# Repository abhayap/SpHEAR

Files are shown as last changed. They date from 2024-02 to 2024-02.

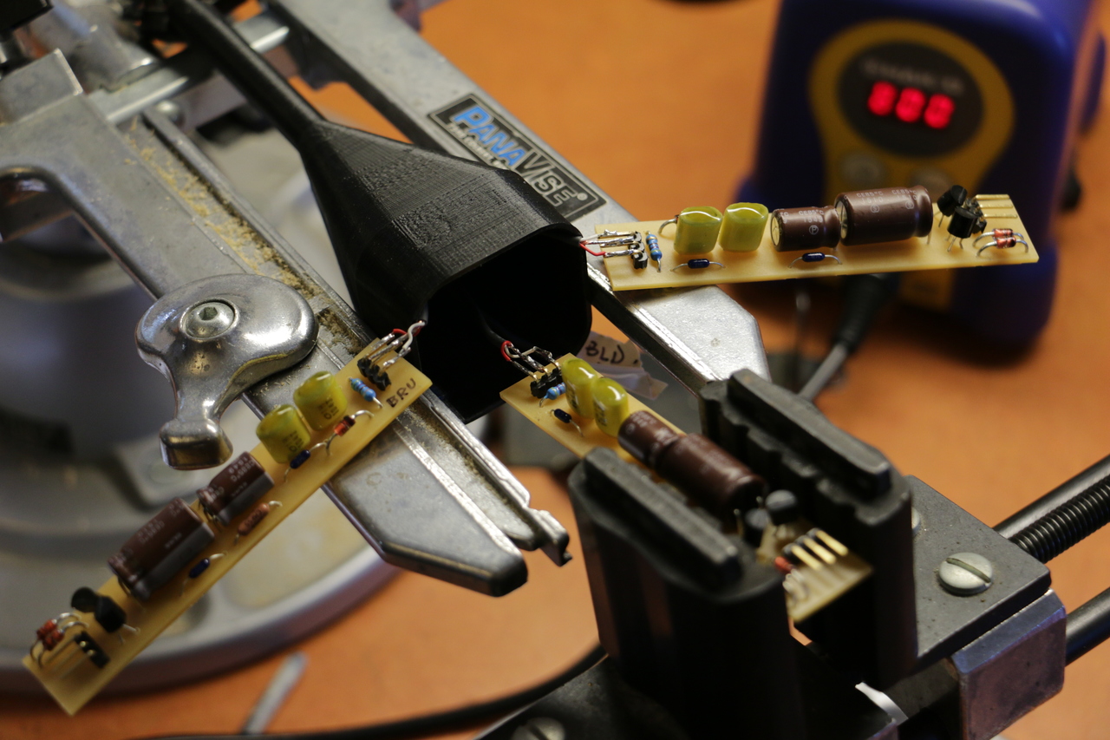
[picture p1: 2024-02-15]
pictures/TinySpHEAR_zapnspark_2.png

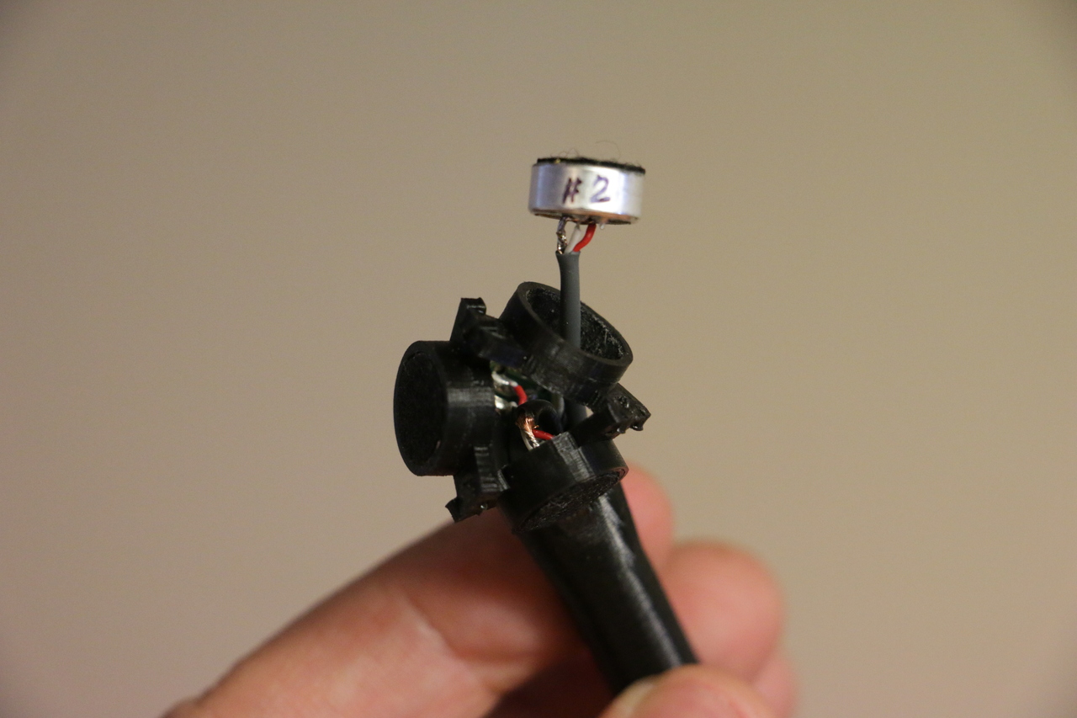
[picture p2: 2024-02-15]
pictures/TinySpHEAR_zapnspark_1.png

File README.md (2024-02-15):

# The *SpHEAR Project

The *SpHEAR (Spherical Harmonics Ear) Project is a collection of 3D models and associated code for building, testing and calibrating full surround Ambisonics microphones. All 3D models are written in Openscad with the code licensed under the GPL 3+ license (GNU Public License version 3 or higher), and the 3D models licensed under the Creative Commons Attribution-NonCommercial-ShareAlike 4.0 International license.

The 3D models are almost completely parametric and are designed to be able to be printed on low cost widely available 3D printers (at CCRMA we use an Ultimaker 2 Extended Plus printer, using PLA material). The design is modular and tries to avoid using overhangs and support structures. That is why each microphone assembly is made of a number of independently printed capsule holders interconnected by legs that interlock and hold the structure together. The capsule holders and the mount are glued together to create a 3D structure that securely holds all microphone capsules. A mount that can be clipped into a standard microphone stand is part of the design.

## Mailing list

You can subscribe to a development mailing list (sphear-devel@ccrma.stanford.edu) here:
<https://cm-mail.stanford.edu/mailman/listinfo/sphear-devel>

## About building microphones

Successfully printing a microphone assembly is only the first step in a long and complicated process. This also includes finding and buying the required microphone capsules, assembling the electronics (requires precision skill with the soldering iron) and finally calibrating the multi-capsule microphone to get the best performance out of it (you will need at least a single driver sound source and a calibrated microphone).

The whole process is not easy and requires knowledge of acoustics and electronics, plus a healthy dose of patience and the ability to perform tasks with precision and care. This repository will eventually include more detailed instructions, electronic schematics, suggested and tested parts and software and procedures for calibrating and measuring the microphone, including models for test and calibration rigs.

## 3D models

The 3D models currently include the TinySpHEAR, a four capsule first order Ambisonics microphone, the Octathingy, an eight capsule second order design by Eric Benjamin and Aaron Heller and preliminary designs for 12 and 20 capsule designs (the BigSpHEAR_12 and BigSpHEAR_20 models). The models will be expanded as testing proceeds. 

* [TinySpHEAR](doc/TinySpHEAR_simple.md): four capsule first order microphone with simple stand mount

  * [TinySpHEAR Zapnspark](doc/TinySpHEAR_zapnspark.md): four capsule first order microphone with four Zapnspark phantom power interfaces and shock mount

* [Octathingy](): eight capsule microphone (proof of concept so far)

* [BigSpHEAR_12 / BigSpHEAR_20](): 12 and 20 capsule designs (proof of concept)

## Electronics

The pcb/zapnspark directory contains the Kicad electrical circuit and printed circuit board design for the Zapnspark phantom power interface. The current printed circuit board design fits into four slots carved inside the body of the [TinySpHEAR plus Zapnspark model](doc/TinySpHEAR_zapnspark.md). Everything is dimensioned for the sizes of the components specified in the parts list, any changes (specially the diameter of the electrolytic capacitors) would need to be taken into account by changing appropriate model parameters. 

## Calibration

The calibration/src directory contains the Octave files for the current calibration software. The CALIBRATION.md file in there has a very brief description of usage, but currently is out of date with the current source code. Look into the individual files for more guidance. Hopefully this will be fixed soon.

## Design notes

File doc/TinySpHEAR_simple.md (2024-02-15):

# The *SpHEAR Project

## TinySpHEAR

The TinySpHEAR microphone is a traditional 4 capsule tetrahedral first order Ambisonics microphone. The picture shows the full design as previewed in OpenSCAD and a picture of the first prototype (built with Primo EM182 10mm capsules, 9.6mm microphone radius). 



The four capsule holders come in two flavors, one for the upper two capsules and another for the bottom two capsules that connect into the microphone mount. The capsule holders have legs with fingers that interlock and hold the structure together. There are two styles of usable interconnections, horizontal legs (easier to print and assemble, a bit bigger) and vertical legs (more difficult to print and assemble but more compact).

Horizontal legs, 10mm capsule, 10mm microphone radius:



Vertical legs, 10mm capsule, 10.6mm microphone radius:



There is a third style of legs intended to print the whole microphone structure in one go in a more sophisticated 3D printer, but this has not been tested.

TinySpHEAR, angled legs TinySpHEAR with angled legs

A couple of configuration variables in the source file can be used to switch to a "print" rendering where the individual parts of the structure are laid flat on the printing surface.

TinySpHEAR ready to print

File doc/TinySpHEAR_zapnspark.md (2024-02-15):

# The *SpHEAR Project

## TinySpHEAR with Zapnspark interfaces

The TinySpHEAR microphone is a traditional 4 capsule tetrahedral first order Ambisonics microphone. This improved design adds four printed circuit boards with Zapnspark phantom power interfaces housed in the microphone body. A trailing cable ends in four XLR connectors. The picture shows the full design as previewed in OpenSCAD and a picture of the second prototype (built with Primo EM182 10mm capsules, 9.6mm microphone radius).



The 3D models also include a shock mount that clips into a standard microphone stand mount. The two main model files are tuned for [EM182](../master/TinySpHEAR_EM182.scad "TinySpHEAR for 10mm EM182 capsules") (10mm) and [EM200](../master/TinySpHEAR_RM200.scad "TinySpHEAR for EM200 capsules") (14mm) capsules. Uncomment the different "render_" lines to render different parts or the complete microphone assembly. 

A few more pictures detailing the assembly process:

Wiring the capsules:



Connecting the capsules with the printed circuit boards:



Sliding the printed circuit boards into the slots in the body:



Connecting to the 4 conductor cable:



Ready to test:



The full microphone including the shock mount:



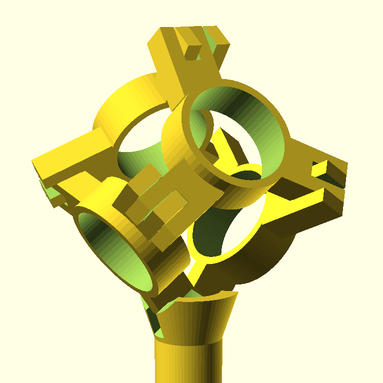
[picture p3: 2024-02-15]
pictures/TinySpHEAR_10mm_hlegs.png

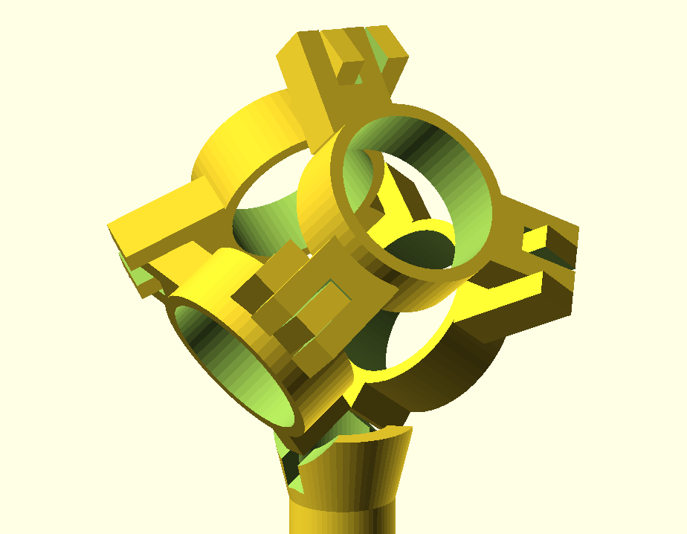
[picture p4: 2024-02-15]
pictures/TinySpHEAR_hlegs_10mm_10mm.png

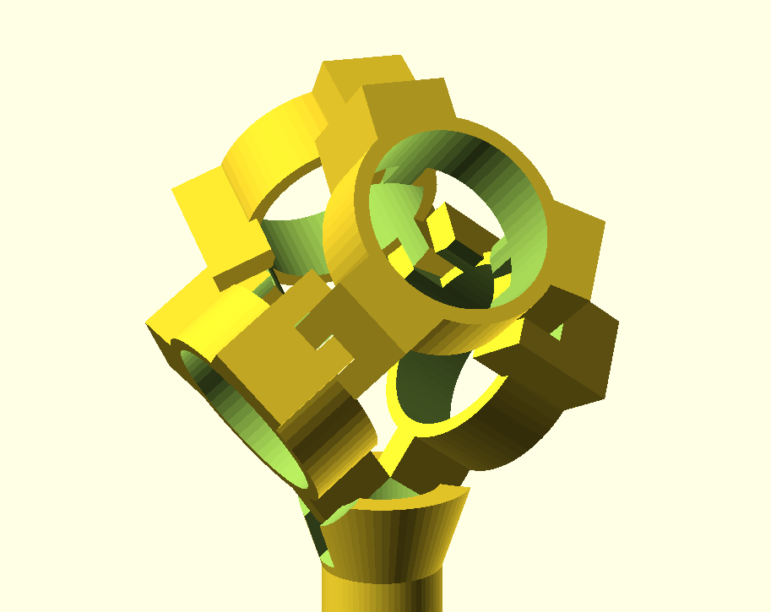
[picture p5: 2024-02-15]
pictures/TinySpHEAR_vlegs_10mm_10mm6.png

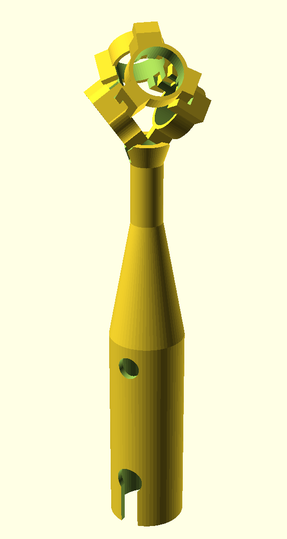
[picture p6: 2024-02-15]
pictures/TinySpHEAR.png

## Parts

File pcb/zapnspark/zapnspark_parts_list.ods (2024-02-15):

Supplier | Supplier part # | Manufacturer part # | Description | PCB | Quantity | Total | Boards | Comment
 |  |  |  |  |  |  | 24
mouser.com | 71-CMF555K1100FKEA | CMF555K1100FKEA | Metal Film Resistors - Through Hole 1/4watt 5.11Kohms 1% | R4 | 1 | 24
mouser.com | 660-MF1/4LCT52R471J | MF1/4LCT52R471J | Metal Film Resistors - Through Hole1/4 WATT 470 OHM 5% | R1 | 1 | 24
mouser.com | 71-CMF502K2100FHEB | CMF502K2100FHEB | Metal Film Resistors - Through Hole 1/8watt 2.21Kohms 1% | R2/R5 | 2 | 48 |  | Correct value for 5V across capsule
mouser.com | 71-CMF50150K00FHEB | CMF50150K00FHEB | Metal Film Resistors - Through Hole1/8watt 150Kohms 1% | R3/R6 | 2 | 48
mouser.com | 555-RFS16V470MG3#5 | RFS-16V470MG3#5 | Aluminum Electrolytic Capacitors - Leaded47uF 16V 20% Audio SILMIC II | C1 | 1 | 24
mouser.com | 555-RFS50V470MH4#5 | RFS-50V470MH4#5 | Aluminum Electrolytic Capacitors - Leaded47uF 50V 20% Audio SILMIC II | C3 | 1 | 24
mouser.com | 647-QYX1H104JTP | QYX1H104JTP | Film Capacitors .1UF 50V 5% | C2/C4 | 2 | 48
 | 512-1N5240BTR | 1N5240BTR | Zener Diodes 10V 0.5W Zener | D2 | 1 | 24
 | 512-BZX79C6V2 | BZX79C6V2 | Zener Diodes 6.2V 0.5W Zener | D1/D3 | 2 | 48
mouser.com | 512-BC559CTA | BC559CTA | Bipolar Transistors – BJT Transistor PNP Epitaxial Silicon | Q1/Q2 | 2 | 48

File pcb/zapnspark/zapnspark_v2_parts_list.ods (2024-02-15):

Supplier | Supplier part # | Manufacturer part # | Description | PCB | Price | Quantity | Total | Boards | Comment
 |  |  |  |  |  |  |  | 24
mouser.com | 71-CMF555K1100FKEA | CMF555K1100FKEA | Metal Film Resistors - Through Hole 1/4watt 5.11Kohms 1% | R4 |  | 1 | 24
mouser.com | 660-MF1/4LCT52R471J | MF1/4LCT52R471J | Metal Film Resistors - Through Hole1/4 WATT 470 OHM 5% | R1 |  | 1 | 24
mouser.com | 71-CMF502K2100FHEB | CMF502K2100FHEB | Metal Film Resistors - Through Hole 1/8watt 2.21Kohms 1% | R2/R5 |  | 2 | 48 |  | correct value for 5V across capsule
mouser.com | 71-CMF50150K00FHEB | CMF50150K00FHEB | Metal Film Resistors - Through Hole1/8watt 150Kohms 1% | R3/R6 |  | 2 | 48
digikey.com | 493-10358-1-ND | UMW1C470MDD1TP | Aluminum Electrolytic Capacitors - Leaded 16volts 47uF 6.3x5 20% 2.5LS | C1 | 0.45 | 1 | 24 |  |  | https://www.digikey.com/product-detail/en/nichicon/UMW1C470MDD1TP/493-10358-1-ND/4312617
digikey.com | 493-10370-1-ND | UMW1H330MDD1TP | Aluminum Electrolytic Capacitors - Leaded 50volts 33uF 8x5 20% 2.5LS | C3/C5 | 0.46 | 2 | 48 |  |  | https://www.digikey.com/product-detail/en/nichicon/UMW1H220MDD1TP/493-10368-1-ND/4312627
mouser.com | 647-QYX1H104JTP | QYX1H104JTP | Film Capacitors .1UF 50V 5% | C2/C4 |  | 2 | 48
 | 512-1N5240BTR | 1N5240BTR | Zener Diodes 10V 0.5W Zener | D2 |  | 1 | 24
 | 512-BZX79C6V2 | BZX79C6V2 | Zener Diodes 6.2V 0.5W Zener | D1/D3 |  | 2 | 48
mouser.com | 512-BC559CTA | BC559CTA | Bipolar Transistors – BJT Transistor PNP Epitaxial Silicon | Q1/Q2 |  | 2 | 48

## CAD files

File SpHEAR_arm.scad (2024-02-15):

//
// Spherical Harmonics Ear Project (*SpHEAR)
//
// Customized WidowXL Robotic Arm Components
// 
// Copyright 2018, Fernando Lopez-Lezcano, All Rights Reserved
// nando@ccrma.stanford.edu
//
//  This program is free software: you can redistribute it and/or modify
//  it under the terms of the GNU General Public License as published by
//  the Free Software Foundation, either version 3 of the License, or
//  (at your option) any later version.
//
//  This program is distributed in the hope that it will be useful,
//  but WITHOUT ANY WARRANTY; without even the implied warranty of
//  MERCHANTABILITY or FITNESS FOR A PARTICULAR PURPOSE.  See the
//  GNU General Public License for more details.
//
//  You should have received a copy of the GNU General Public License
//  along with this program.  If not, see <http://www.gnu.org/licenses/>.
//
// 3d Models released under the Creative Commons license as follows:
//   Attribution-NonCommercial-ShareAlike 4.0 International (CC BY-NC-SA 4.0)
// http://creativecommons.org/licenses/by-nc-sa/4.0/

facets = 128;

s5_plate_w = 47.0;
s5_plate_d = 29.0;
s5_plate_t = 5.9 + 4.5;

s5_mount_hole_w = 38.0;
s5_mount_hole_d = 22.0;

// holes for mounting to arm plate
s5_hole_r = 2.7/2;

// center hole for servo plate
s5_center_hole_d = 8.5;

// holes to mount servo to plate
module s5_plate_holes () {
    for (mw = [0, 1]) mirror([mw, 0, 0]) {
        for (md = [0, 1]) mirror([0, md, 0]) {
            translate([s5_mount_hole_w/2, s5_mount_hole_d/2, -1.0]) {
                cylinder(r = s5_hole_r + 0.15, h = 20.0, $fn = facets);
            }
        }
    }
}

// holes to mount adaptor to servo
module s5_servo_holes () {
    translate([0, 0, -0.01]) {
        // center hole for servo
        cylinder(r = 6.5/2, h = 20.0, $fn = facets);
        // holes for mounting servo to plate
        for (m = [0, 1]) mirror([m, 0, 0]) {
            translate([15, -4.5, 0]) {
                cylinder(r = s5_hole_r, h = 20.0, $fn = facets);
                cylinder(r = 5/2, h = 3.25, $fn = facets);
            }
            translate([15, - 4.5 + 17, 0]) {
                cylinder(r = s5_hole_r, h = 20.0, $fn = facets);
                cylinder(r = 5/2, h = 3.25, $fn = facets);
            }
        }
    }
}

// basic mounting plate
module s5_plate () {
    difference() {
        mp_r = 2.0;
        union() {
            translate([-s5_plate_w/2 + mp_r, -s5_plate_d/2 + mp_r, 0]) {
                intersection() {
                    minkowski() {
                        cube([s5_plate_w - 2*mp_r, s5_plate_d - 2*mp_r, s5_plate_t]);
                        cylinder(r = mp_r, h = 0.001, $fn = facets);
                    }
                    // rounded top
                    translate([0, 0, -mp_r]) minkowski() {
                        cube([s5_plate_w - 2*mp_r, s5_plate_d - 2*mp_r, s5_plate_t]);
                        sphere(r = mp_r, $fn = facets);
                    }
                }
            }
            // extended support for plate screws
            for (m = [0, 1]) mirror([m, 0, 0]) translate([15, - 4.5 + 17, 0]) {
                cylinder(r = 7/2, h = 5.5, $fn = facets);
            }
        }
        // hollow out servo space
        s_w = 24.40;
        translate([-s_w/2, -12.50, 5.5/2]) {
            cube([s_w, 40, 10]);
        }
        // and shave top as well
        s_tw = 35.60;
        m_r = 6.0;
        translate([-s_tw/2 + m_r, -12.50 + m_r, 5.5 - 0.2]) {
            minkowski() {
                cube([s_tw - 2*m_r, 40, 10]);
                cylinder(r = m_r, h = 0.001, $fn = facets);
            }
        }
    }
}

// plate that screws into MX28T servo and has sockets to attach
// to microphone mount

module arm_attachment_plate () {
    // 25.0 is separation between sockets
    plate_w = grip_sep * 2 + arm_l + 4 * wall;
    plate_d = arm_w + 4 * wall;
    plate_t = 5.0;
    translate([-plate_w/2, -plate_d/2, 0]) {
        cube([plate_w, plate_d, plate_t]);
    }
}

// holes for MX28T servo
module arm_attachment_holes () {
    // center of servo
    translate([0, 0, -0.01]) cylinder(r = 9.0/2, h = 10.0, $fn = facets);
    // screw holes
    for (r = [45, -45, 135, -135]) rotate([0, 0, r]) {
        translate([8.0, 0, -0.01]) {
            cylinder(r = 2.7/2, h = 10.0, $fn = facets);
        }
        translate([8.0, 0, 3.25]) {
            cylinder(r = 3.9/2, h = 10.0, $fn = facets);
        }
    }
}

// model WidowXL (dimensions of original gripper)

wall = 1.0;

// sliding block (dimensions from WidowXL gripper blocks)
arm_l = 10.2 + 0.38;
arm_w = 21.5 + 0.38;
// x profile
arm_profile_s = 10.25;
arm_b_prof = 4.25;
// connection socket
arm_s_h = 21.0;

// separation between centers of sockets
grip_sep = 25.4 * 1.5 / 2 + arm_l / 2;

// block that can be screwed to existing gripper of stock WidowXL arm
module arm_gripper_block () {
    translate([-arm_l/2, -arm_w/2, 0]) difference() {
        // body
        translate([-(4 * wall)/2, -2 * wall, 0]) {
            cube([arm_l + 4 * wall, arm_w + 4 * wall, arm_s_h]);
        }
        // carve out corners for better fit
        translate([0.2, 0.2, 0]) cylinder(r = 0.4, h = arm_s_h, $fn = facets);
        translate([arm_l, 0.2, 0]) cylinder(r = 0.4, h = arm_s_h, $fn = facets);
        translate([arm_l, arm_w, 0]) cylinder(r = 0.4, h = arm_s_h, $fn = facets);
        translate([0.2, arm_w, 0]) cylinder(r = 0.4, h = arm_s_h, $fn = facets);
        // arm gripper block
        union() {
            cube([arm_l, arm_w, arm_s_h + 0.1]);
            translate([-arm_l/2, arm_w/2 - arm_profile_s/2, - arm_b_prof - arm_profile_s - 10]) {
                cube([20, arm_profile_s, arm_profile_s + 10]);
            }
        }
    }
}

// MX28T servo mounting plate
//
// attaches MX28T servo to arm to act as wrist rotation servo with 360 degree
// of rotation instead of the stock dual AX12A wrist rotation and gripper servos
// with 300 degree rotation limit

*difference() {
    s5_plate();
    s5_plate_holes();
    s5_servo_holes();
}

// microphone mount attachment, screws into MX28T servo and has sockets
// for the microphone mount pillars

difference() {
    union() {
        arm_attachment_plate();
        for (m = [0, 1]) mirror([m, 0, 0]) translate([grip_sep, 0, 5.0]) arm_gripper_block();
    }
    arm_attachment_holes();
}

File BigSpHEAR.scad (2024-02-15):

//
// BigSpHEAR (Big Spherical Harmonics Ear), 12 capsule Ambisonics microphone
//
// Copyright 2015, Fernando Lopez-Lezcano, All Rights Reserved
// nando@ccrma.stanford.edu
//
//
//  This program is free software: you can redistribute it and/or modify
//  it under the terms of the GNU General Public License as published by
//  the Free Software Foundation, either version 3 of the License, or
//  (at your option) any later version.
//
//  This program is distributed in the hope that it will be useful,
//  but WITHOUT ANY WARRANTY; without even the implied warranty of
//  MERCHANTABILITY or FITNESS FOR A PARTICULAR PURPOSE.  See the
//  GNU General Public License for more details.
//
//  You should have received a copy of the GNU General Public License
//  along with this program.  If not, see <http://www.gnu.org/licenses/>.
//
//
// 3d Models released under the Creative Commons license as follows:
//   Attribution-NonCommercial-ShareAlike 4.0 International (CC BY-NC-SA 4.0)
// http://creativecommons.org/licenses/by-nc-sa/4.0/


////
//// model parameters

// dimensions of the EM182 electret microphone
capsule_radius = 5;
capsule_height = 4.5;

// distance between face of capsule and center of array
mic_radius = 20;

// dimensions of capsule holder connection legs
leg_width = 4;
leg_thick = 2.5;

// width of the ridge that connects to the mount
ridge_width = 2;
ridge_length = 2;

// wall thickness of capsule holder
wall = 1;

// dimensions of microphone holder
mount_radius = 4.5;

// height of mount
mount_height = 4;

// type of octathingy
// 0 -> regular octathingy (equilateral triangles in the square antiprism)
// 1 -> tetrahedral compatible octathingy (same elevation angle as the tetrahedral mic)
tetra_compat = 0;

//// end of model parameters
////
//// rendering control

// what to render:
// 0 -> ready to print
//   set = 0 -> one capsule, set = 1 -> four capsules
// 1 -> the whole microhone with four capsules
rendermic = 1;
renderset = 0;

// what type of connection to use between capsule holders:
// 0 -> original cylinder beams
// 1 -> interlocking beams (out)
// 2 -> interlocking beams (in)
connect = 1;

// adjustment for the radius of the capsule
//   measured inside diameter of a trial print was around 7.5 to 8.2 
//   instead of 10, capsule diameter was 9.99)
fudge = 0.15;

// adjustment for fit of slots in connection legs and mount
fit = 0.2;

// number of facets for rendering cylinders
facets = 64;

//// end of rendering control
////

// define the elevation angle of the upper and lower rings
//
// http://eusebeia.dyndns.org/4d/antiprism4
//
// The Cartesian coordinates of the square antiprism, 
// centered on the origin and having edge length 2, are:
//
//    (0, ±√2, 1/∜2)
//    (±√2, 0, 1/∜2)
//    (±1, ±1, −1/∜2)
//
// the elevation angle for the two rings of 4 is:
//
// 1/2*∜2 = 0.420448207627 (z for edge length = 1)
// atan(1/(2*∜2) / 0.707) = 30.7358671024
elev_angle =  tetra_compat == 0 ? atan(1 / (2 * sqrt(sqrt(2))) * sqrt(2)) : atan(sqrt(1/2));

// calculate half angle between vertices in the square antiprism
// these angles define the length of the connecting legs
//
// z coordinate of antiprism vertices
vert_z = sqrt(2) * tan(elev_angle) / 2;
// vector length (same for all antiprism vertices)
vert_n = norm([-0.5, -0.5, vert_z]);
// half angle between adjacent vertices in either the upper or lower rings
vert_angle_h = acos(([-0.5, -0.5, vert_z] / vert_n) * ([0.5, -0.5, vert_z] / vert_n)) / 2;
// half angle between adjacent vertices in the upper and lower rings
vert_angle_v = acos(([0.0, -1 / sqrt(2), -vert_z] / vert_n) * ([0.5, -0.5, vert_z] / vert_n)) / 2;

// microphone holder geometry
capsule_sep_min = (mic_radius - capsule_height) * cos(elev_angle) - (capsule_radius + wall) * sin(elev_angle);
capsule_sep_max = mic_radius * cos(elev_angle) - (capsule_radius + wall) * sin(elev_angle);
capsule_bottom = mic_radius * sin(elev_angle) + (capsule_radius + wall) * cos(elev_angle);
mount_slot_depth = ridge_length * sin(elev_angle);

////////
// microphone capsule holder

// azimuth: horizontal orientation of the capsule
// elevation: vertical orientation of the capsure
// mounts: vectors containing the angle of the mount and the angle to the adjacent capsule
// twist: rotate the whole capsule to match mounting legs

module capsule (azimuth, elevation, mounts, twist, ridge) {
	rotate([0, 0, azimuth]) {
		rotate([0, (90 - elevation), 0]) {
  			translate([0, 0, rendermic == 0 ? 0 : mic_radius - capsule_height]) {
				difference () {
					union () {
						// main capsule holder
						cylinder(r = capsule_radius + wall, h = capsule_height, $fn = facets);	
						// the mounting legs
						for (angles = mounts) {
							rotate([0, 0, angles[0] + twist]) {
								// connect with cylindrical beams, very pretty
                                leg_length = mic_radius * sin(angles[1]) - (capsule_radius + wall) * cos(angles[1]) + wall;
								if (connect == 0) {
									translate([capsule_radius - wall, 0, capsule_height - wall]) {
										rotate([0, 180 - (90 - angles[1]), 0]) {
											cylinder(d = leg_width, h = leg_length - 0.1, center = false, $fn = facets);
										}
									}
								}
								// connect with horizontal legs
								if (connect == 1) {
                                    leg_length = (mic_radius - capsule_height + leg_thick) * tan(angles[1]) - capsule_radius;
                                    slot_depth = leg_thick * cos(90 - 2 * angles[1]) + fit;
									translate([capsule_radius + leg_length + fudge, - leg_width / 3, 0]) {
										rotate([0, -90, 0]) {
											difference() {
												// thickness, width
												cube([leg_thick, leg_width, leg_length]);
												// cut slot in connector
												translate([0, leg_width / 3 - (fit / 2), 0]) {
													cube([leg_thick, leg_width / 3 + fit, slot_depth]);
												}
											}
										}
									}
								}
								// connect with vertical legs
								if (connect == 2) {
                                    leg_length = (mic_radius * tan(angles[1]) - capsule_radius) * tan(90 - angles[1]); 
                                    slot_depth = leg_thick * (cos (90 - 2 * angles[1]) + tan(90 - 2 * angles[1])) + fit;
									translate([capsule_radius + fudge, - leg_width / 3, - leg_length + capsule_height]) {
										difference() {
											// thickness, width
											cube([leg_thick, leg_width, leg_length]);
											// cut slot in connector
											translate([0, leg_width / 3 - (fit / 2), 0]) {
												cube([leg_thick, leg_width / 3 + fit, slot_depth]);
											}
										}
									}
								}
							}
						}
						// add ridges for microphone mount
						if (ridge == 1) {
							rotate([0, 0, twist]) {
								translate([capsule_radius + fudge, - wall , 0]) {
									difference() {
										cube([ridge_length, ridge_width, capsule_height], center = false);
										//rotate([0, 90 - elev_angle, 0]) {
										//	cube([ridge_length, ridge_width, capsule_height], center = false);
										//}
									}
								}
							}
						}
					}
					// make the hole for the capsule
					translate ([0, 0, -2]) {
						cylinder(r = capsule_radius + fudge, h = capsule_height + 2, $fn = facets);
					}
					// remove any extra connecting beam material from the face of the holder
					if (connect == 0) {
						translate ([0, 0, capsule_height]) {
							cylinder(r = capsule_radius + wall * 2, h = 2, $fn = facets);
						}
					}
				}
			}
		}
	}
}

// microphone mount
//
// angles: angles for mount slots
// wall: thickness of cylinder wall
// separation: height of mount with respect of the microphone assembly
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

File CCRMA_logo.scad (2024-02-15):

// Module names are of the form poly_<inkscape-path-id>().  As a result,
// you can associate a polygon in this OpenSCAD program with the corresponding
// SVG element in the Inkscape document by looking for the XML element with
// the attribute id="inkscape-path-id".

// fudge value is used to ensure that subtracted solids are a tad taller
// in the z dimension than the polygon being subtracted from.  This helps
// keep the resulting .stl file manifold.

// rendered from svg version of the CCRMA logo
// http://www.instructables.com/id/Make-a-3D-print-from-a-2D-drawing/

module poly_path_ccRMA(h)
{
  scale([25.4/90, -25.4/90, 1]) union()
  {
    translate([55, 0, 0]) {
    linear_extrude(height=h)
        // had to break this into two polygons to avoid an invalid two-manifold error
        polygon([[-15.081100,-7.095502],[-35.138500,26.363802],[-59.835400,26.376802],[-75.952000,4.113902],[-75.965000,26.351602],[-85.955700,26.351602],[-85.955700,-26.482702],[-65.861500,-26.466702],[-65.460900,-26.425702],[-63.971100,-26.229302],[-61.153300,-25.494402],[-58.515200,-24.297802],[-55.050912,-21.710252],[-52.385300,-18.343002],[-50.908000,-15.057839],[-50.212500,-11.483402],[-50.174500,-11.020602],[-50.174500,-10.293702],[-50.174500,-9.566902],[-50.212500,-9.091402],[-50.590325,-6.653826],[-51.343600,-4.309098],[-51.505700,-3.908498],[-51.802500,-3.307398],[-52.099200,-2.706298],[-52.383600,-2.230698],[-55.060700,1.148702],[-55.520100,1.596302],[-55.945800,1.950802],[-59.019287,4.003015],[-62.409800,5.319402],[-62.745200,5.419402],[-62.776200,5.438402],[-54.868700,16.348102],[-40.671600,16.361102],[-15.072900,-26.343702]]);
        linear_extrude(height=h)
        polygon([[-15.072900,-26.343702],[-5.303400,-26.356702],[-5.290400,7.151802],[14.802700,-26.330302],[14.846700,-26.381302],[24.693900,-26.381302],[24.693900,16.486202],[38.665900,16.486202],[38.665900,-26.356302],[48.644100,-26.355902],[85.955700,26.442702],[14.828400,26.482702],[14.815400,-7.131802],[-5.278800,26.391602],[-5.316800,26.476602],[-15.069600,26.476902],[-15.082600,-7.095002]]);
        }
    }
}

module poly_path_cCrma(h)
{
  scale([25.4/90, -25.4/90, 1]) union()
  {
    linear_extrude(height=h)
      polygon([[-65.385800,26.326552],[-66.049300,26.290552],[-70.615044,25.661893],[-74.969475,24.330877],[-79.036019,22.327824],[-82.738100,19.683052],[-86.195363,16.169577],[-88.928200,12.118952],[-90.153452,9.548833],[-91.075563,6.884702],[-91.692592,4.133421],[-92.002600,1.301852],[-92.027600,0.838652],[-92.027600,-0.025248],[-92.027600,-0.889048],[-92.002600,-1.352248],[-91.647816,-4.440594],[-90.925775,-7.435751],[-89.839872,-10.326658],[-88.393500,-13.102252],[-85.797338,-16.690389],[-82.590600,-19.852452],[-80.192920,-21.643505],[-77.613713,-23.168027],[-74.877473,-24.413286],[-72.008700,-25.366552],[-69.142063,-25.994277],[-65.999200,-26.346452],[-65.548500,-26.377452],[-64.334100,-26.377452],[-63.119700,-26.377452],[-62.506200,-26.334452],[-56.860600,-25.414264],[-51.626600,-23.438152],[-48.455700,-21.608614],[-45.517000,-19.343552],[-45.091300,-18.971252],[-44.338500,-18.219052],[-43.585700,-17.466852],[-43.286300,-17.128852],[-41.315138,-14.657339],[-39.670300,-11.961652],[-52.305200,-11.945652],[-54.994400,-14.014752],[-58.733175,-15.742652],[-62.831800,-16.530352],[-63.244900,-16.560352],[-64.021100,-16.560352],[-64.797400,-16.560352],[-65.210500,-16.530352],[-68.095522,-16.080916],[-70.824750,-15.174740],[-73.338428,-13.837369],[-75.576800,-12.094352],[-77.221838,-10.346877],[-78.569500,-8.412352],[-78.847900,-7.946952],[-79.126400,-7.385752],[-79.405000,-6.824552],[-79.571100,-6.423852],[-80.647000,-2.442548],[-80.707000,-1.991848],[-80.749000,-1.428548],[-80.791000,-0.865148],[-80.777000,-0.101448],[-80.763000,0.662252],[-80.726000,1.050452],[-80.281381,3.597747],[-79.448000,6.002965],[-78.235194,8.244925],[-76.652300,10.302452],[-76.336300,10.653052],[-75.888200,11.088552],[-75.440000,11.524152],[-75.064200,11.840852],[-73.221520,13.196829],[-71.235413,14.283939],[-69.122948,15.094282],[-66.901200,15.619952],[-65.298600,15.813552],[-64.822900,15.851552],[-64.021600,15.851552],[-63.220400,15.851552],[-62.744600,15.813552],[-61.004400,15.596352],[-58.679488,15.015135],[-56.461375,14.114464],[-54.396375,12.917038],[-52.530800,11.445552],[-52.307700,11.241452],[-39.316000,11.241452],[-41.057225,14.199627],[-43.149900,16.922452],[-43.514300,17.338352],[-44.077700,17.911752],[-47.257700,20.708452],[-51.993000,23.568539],[-57.209200,25.451452],[-62.606900,26.291152],[-62.995000,26.317152],[-64.096700,26.327152],[-65.386300,26.326852]]);
  }
}

module poly_path_Ccrma(h)
{
  scale([25.4/90, -25.4/90, 1]) union()
  {
    linear_extrude(height=h)
      polygon([[-123.777800,26.163952],[-128.367003,25.564632],[-132.746000,24.262140],[-136.834522,22.287554],[-140.552300,19.671952],[-144.146888,16.049877],[-146.965300,11.856152],[-148.153255,9.341083],[-149.049413,6.734027],[-149.654964,4.030708],[-149.971100,1.226852],[-150.000100,0.738652],[-149.999600,-0.187848],[-149.999000,-1.114348],[-149.971000,-1.577548],[-149.462575,-5.385525],[-148.408900,-9.014252],[-146.825211,-12.443858],[-144.754163,-15.615802],[-142.233733,-18.480171],[-139.301900,-20.987052],[-136.504220,-22.809804],[-133.519163,-24.283739],[-130.373773,-25.397432],[-127.095100,-26.139452],[-123.840000,-26.493952],[-123.339200,-26.522952],[-122.325100,-26.522952],[-121.311000,-26.522952],[-120.810200,-26.493952],[-117.555100,-26.139452],[-112.246205,-24.726477],[-107.377813,-22.358377],[-103.084464,-19.117539],[-99.500700,-15.086352],[-97.437200,-11.721152],[-97.285300,-11.418052],[-110.286700,-11.418052],[-110.615700,-11.726452],[-112.350322,-13.145924],[-114.255700,-14.319677],[-118.469000,-15.872052],[-121.073100,-16.254052],[-121.486300,-16.284052],[-122.287600,-16.283552],[-123.088800,-16.283152],[-123.476900,-16.253152],[-127.196625,-15.578602],[-130.613200,-14.139652],[-133.894100,-11.755652],[-134.282900,-11.397752],[-134.570500,-11.088452],[-135.415200,-10.133652],[-136.818903,-8.134094],[-137.886700,-5.978413],[-138.611972,-3.683025],[-138.988100,-1.264348],[-139.026100,-0.788848],[-139.026100,-0.071148],[-139.026100,0.646552],[-138.987100,1.118452],[-138.602425,3.577752],[-137.844700,5.922152],[-137.670500,6.347852],[-137.385200,6.923752],[-137.100000,7.499652],[-136.834900,7.946352],[-134.148500,11.345552],[-133.651300,11.831552],[-133.289900,12.134052],[-130.250438,14.180402],[-126.881500,15.510952],[-123.538700,16.090352],[-123.063000,16.128352],[-122.274200,16.128652],[-121.485500,16.128852],[-120.984700,16.089852],[-116.953300,15.300652],[-113.897638,13.969465],[-111.172200,12.071352],[-110.849700,11.794652],[-97.660400,11.794652],[-97.865200,12.191152],[-100.606267,16.181861],[-104.035938,19.621302],[-108.053664,22.425193],[-112.558900,24.509252],[-116.660775,25.645565],[-120.944600,26.167252],[-121.455300,26.192252],[-122.421900,26.192252],[-123.388500,26.192252],[-123.776600,26.172252]]);
  }
}

module poly_path_wave(h)
{
  scale([25.4/90, -25.4/90, 1]) union()
  {
    linear_extrude(height=h)
      polygon([[133.915800,14.633452],[133.542500,14.597452],[131.587200,14.164852],[129.843112,13.359130],[128.153325,12.131177],[124.551900,8.075652],[121.605800,3.876752],[116.754800,-2.664148],[116.413200,-3.037648],[116.067600,-3.358048],[114.688037,-4.419673],[113.345900,-4.936348],[113.108000,-4.987348],[112.730000,-5.000348],[112.352000,-5.013348],[112.104100,-4.984348],[109.903000,-4.257848],[107.948912,-2.979860],[105.749500,-1.026648],[102.290800,2.805352],[101.218000,4.094852],[100.421400,4.983752],[97.458400,2.404552],[97.835500,1.950652],[99.637100,-0.199348],[104.214900,-5.015348],[107.951150,-7.710776],[109.727850,-8.481364],[111.509200,-8.902152],[111.780900,-8.940152],[112.382400,-8.955152],[112.984000,-8.970152],[113.371500,-8.927152],[116.009862,-8.191914],[118.466500,-6.528852],[118.792000,-6.241052],[119.268400,-5.755552],[121.529775,-3.103611],[124.958600,1.769752],[127.745900,5.740052],[129.875975,8.308627],[131.687900,9.851652],[131.912700,9.995352],[132.263200,10.167652],[132.613800,10.339852],[132.867100,10.426852],[133.120400,10.513852],[133.405400,10.576852],[133.690500,10.639852],[133.933600,10.665852],[134.176800,10.691852],[134.454200,10.691852],[134.731600,10.691852],[134.974700,10.665852],[137.371300,9.928152],[137.746900,9.744352],[138.097400,9.534752],[141.436900,6.898852],[144.775500,2.917552],[146.557700,0.582052],[146.927000,0.124452],[146.983000,0.168452],[149.933100,2.547952],[150.000100,2.609952],[149.556500,3.164952],[148.101800,5.071552],[145.443600,8.428652],[143.168500,10.690352],[139.280250,13.396440],[137.376381,14.177022],[135.481400,14.585052],[135.143400,14.625052],[134.580000,14.635052],[133.916400,14.634452]]);
  }
}

module ccrma_logo(h)
{
   poly_path_Ccrma(h);
   poly_path_cCrma(h);
   poly_path_ccRMA(h);
   poly_path_wave(h + 0.15);
}

*ccrma_logo(1.75);

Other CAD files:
BigSpHEAR_20.scad
Octathingy.scad
Octathingy_EM182.scad
Octathingy_EM200.scad
Octathingy_common.scad
Octathingy_mount_pcb.scad
SpHEAR_common.scad
SpHEAR_windscreen.scad
TestRig.scad
TinySpHEAR_EM182.scad
TinySpHEAR_EM200.scad
TinySpHEAR_H2N_EM200.scad
TinySpHEAR_H2N_common.scad
TinySpHEAR_common.scad
TinySpHEAR_mount_pcb.scad
TinySphEAR.scad
attic/test_rig_gimbal_clip.scad
db25.scad
threads.scad

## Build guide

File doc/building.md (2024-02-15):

# The *SpHEAR Project

# Requirements

## Hardware

### Basic

* A 3D printer (we use an Ultimaker Extended Plus and PLA filament)

* A PCB (printed circuit board) prototyping system (we use the OtherMill computer controlled mill)

### Tools

* X-Acto knife or similar with set of blades (for trimming and cleaning up 3D prints)

* Needle file set (for trimming and cleaning up 3D prints)

* Soldering iron with temperature control and fine tip (for assembling the phantom power interfaces)

* Long nosed pliers

* Wire stripper

* Wire cutter

* Digital Multimeter with hFE measuring function (transistor forward current gain - for matching phantom power interface transistors)

* Headband Magnifying glass (this project has a lot of very small things you need to see, solder and manipulate)

### Calibration equipment

* Speaker: preferably a wide bandwidth single driver small speaker (we have used a H&K M50 with a frequency response of 100 to 20KHz +/- 5dB). If your speaker is small but ported it is best to plug the ports. This speaker is used to measure the response of the completed Ambisonics microphone (and reference microphone) during the calibration.

* Reference microphone: a flat omnidirectional reference microphone, preferably with its own calibrated response. We use this as a reference for calibrating the TinySpHEAR Ambisonics microphone. I have been using an individually calibrated Dayton EM-6 Electret Measurement Microphone. You can buy a very reasonably priced and calibrated EM-6 here:

<http://cross-spectrum.com/measurement/calibrated_dayton.html>

* A Big Room: you need a relatively big space for doing the calibration measurements (or an anechoic chamber, of course). If the room is not anechoic the distance between the nearest reflecting surface, the microphone and the speaker will determine the usable impulse response length (in the space I am using I get 5 to 6 mSecs of usable impulse response which is apparently enough for a reasonable calibration). 

## Software

All the software used to design and build the microphones is Free Software under various licenses and runs under the GNU/Linux operating system. At the time of this writing I'm running this software on Fedora 24 in my laptop (most of the software described below is available either from the Fedora repositories or from the Planet CCRMA repository). 

### 3D Printing and Printed Circuit Design

* **Openscad**: 3D design language and renderer. All 3D models in this project are created in Openscad. 

<http://www.openscad.org/>

* **3D printer slicer**: this is a tool that takes the STL (STereoLithography) output from a rendered Openscad object and outputs the G-code that the 3D printer understands. You will need software that supports the 3D printer you have access to. We use Cura as that is tailored to the printer we have (Ultimaker Plus Extended).

<https://ultimaker.com/en/products/cura-software>

* **Kicad**: schematic capture and printed circuit layout software. This is used to create the phantom power printed circuit boards that connect each capsule to one input of a four channel preamplifier or recorder. The Gerber format export from the printed circuit layout software is used to mill or etch the printed circuit boards. 

<http://kicad-pcb.org/>

### Calibration

* **Aliki**: an integrated system for Impulse Response measurements, using the logaritmic sweep method. This is used to capture the impulse responses of the reference microphone and the finished TinySpHEAR Ambisonics microphone array which are then used to calibrate the microphone. 

<http://kokkinizita.linuxaudio.org/linuxaudio/downloads/>

* **Octave**: a scientific programming language with a powerful mathematics-oriented syntax with built-in plotting and visualization tools. Most of the calibration software is written in Octave. In addition to the base software you will also need to install the "Signal" package. 

<https://www.gnu.org/software/octave/>

* **DRC (Digital Room Correction)**: a program used to generate correction filters for acoustic compensation of HiFi and audio systems in general, including listening room compensation. This is used to calibrate the excitation speaker using the calibrated reference microphone

<http://drc-fir.sourceforge.net/>

* **SOX**: the Swiss Army knife of sound processing programs. Used during the calibration process to convert soundfile formats. 

<http://sox.sourceforge.net/>

* **Ecasound**: a software package designed for multitrack audio processing. Together with Python and Pyecasound it is (optionally) used to measure the final FIR calibration matrix as deployed in TetraProc. 

<http://www.eca.cx/ecasound/>

### Running

You will need software that processes the A-format signals that the microphone outputs into the B-format Ambisonics signals (and that can use the output of our calibration process). 

* **TetraProc**: TetraProc converts the A-format signals from a tetrahedral Ambisonic microphone into B-format signals ready for recording. The calibration process generates a 4x4 matrix of FIR filters that can be directly loaded into TetraProc. TetraProc is a very capable front end for the TinySpHEAR Ambisonics microphone. 

<http://kokkinizita.linuxaudio.org/linuxaudio/downloads/>

## Building the microphone

As outlined in the introduction this is not an easy to build project. It is assumed in these instructions that you have previous experience with 3D printing, precision printed circuit circuit and connector soldering skills and have a steady hand and a lot of patience. The reward at the end of the road is a calibrated Ambisonics microphone with very good performance. 

You will need access to a 3D printer. Plan on doing many experiments as you learn the ins and outs of the particular printer you are using. You will probably need to tweak model parameters so that all the parts fit together nicely.

There are at this point two different types of microphone bodies depending on the type of electrical interface you choose. The simplest one connects the capsule array directly to a standard clip on microphone stand and includes no electronics. The interface to the phantom power supply is just a few components that usually fit into the shell of the XLR connector. This is very simple but the output is not balanced so cable runs have to be short, and is very sensitive to noise in the phantom power supply (for example it leads to unacceptable low frequency performance when using a Zoom F8 recorder). 

By far the best design (and of course the most complicated) uses a balanced phantom power interface derived from the well known Shoeps interface (by Zapnspark). The main body of the microphone assemble houses four of these interfaces. There is an upper "flare" that snaps into place and holds the array of four capsules. Four shielded cables connect the capsules to the printed circuit boards. There is a second lower "flare" that has two design options. The simplest one directly connects a 4 pair balanced snake cable to the printed circuit boards (microphone and cable are a single unit), the second option houses a 12 pin DIN connector that enables the microphone to be disconnected from the cable, but is more expensive. 

For our prints we have used an Ultimaker Plus Extended with PLA filament. 

If you want to build the phantom power printed circuit boards from scratch you will need access to PCB prototype manufacturing equipment. We have used the small OtherMill computer controlled mill with success. 

## Parts list

This is a probably incomplete list of what you will need to build a complete microphone. Some of the items below are optional and depend on which type of mount you want to build. 

* electret capsules: in our prototypes we have used either the Primo 10mm EM182 (approximately U$S 8.50 each) or 14mm EM200 capsules (approximately U$S 16 each). The 3D models are dimensioned for both capsules. The 10mm capsules allow for the smallest array radius (around 9.6mm) and highest transition frequency. The 14mm capsules have a lower transition frequency as the array radius is bigger (around 11mm), but their low frequency response is much better - and they are more expensive. 

* components for building the Zapnspark phantom power interfaces. See the full list in this spreadsheet:

pcb/zapnspark/zapnspark_parts_list.xlsx

Plan on buying at least three or four times the number of transistors needed (8 for a complete four capsule microphone), you want to be able to match them by measuring their hFE using the digital multimeter so that each pair has the closest hFE values possible. You will get the best balanced performance if they are matched - that is also why some of the resistors are 1% tolerance.

_Please be aware that the geometry of the body of the microphone assembly is optimized for the exact size of the printed circuit board and those exact components (specially the diameter of the electrolitic capacitors). If the components you buy are different the completed printed circuit board may not fit inside the microphone body._

* Mogami W2490 Ultraflexible Miniature Microphone Cable - for connecting the capsules and 12 pin connector (if used) to the phantom power printed circuit boards, the 3D models are dimensioned to use this cable

<http://www.mogamicable.com/category/bulk/ultra_flex_mini/>

* Mogami W2931 Analog 4 Pair Audio Snake Cable Black - for connecting the microphone to the XLR audio connectors, 3D models assume use of this cable

<http://www.mogamicable.com/category/bulk/snake/>

* Amphenol Part Number: T 3635 002, male to cable connector, for cable diameter 6-8 mm, solder termination, gold plated contacts (only the inner core is used, housed in the bottom flare of the microphone assembly).

<http://www.mouser.com/ProductDetail/Amphenol/T-3635-002/?qs=%2fha2pyFaduj9RozDj9VGZwhE1bng9mEr%2fVqLjk4F3KI%3d>

* Amphenol Part number: T 3636 002, female to cable connector for cable diameter 6-8 mm, solder termination, gold plated contacts (this is used to build the cable that splits the microphone output into separate XLR connectors).

<http://www.mouser.com/ProductDetail/Amphenol-Tuchel/T-3636-002/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>

* Switchcraft or Amphenol XLR connectors (four), male to cable

* screw and nut for shock mount (screw: 10/24 x 3/4 Trimmed, Hex Steel GR8 Cap Screw, B2032024; nut: #10 Thumbnut, 5/8"Diameter Black Knurl Style Knob, 10/24 Custom aluminum nut)

* black short hair ties for assembling shock mount (scünci 15975-A or similar)

* Switchcraft Mini-XLR Connectors 8 pin, male, TA8MSHF (Mouser #502-TA8MSHF) - for proposed H2N new design

## 3D Printing the parts

There are two top level Openscad files, each one optimized for one of the two Primo capsules we have used:

* TinySpHEAR_EM182.scad (Primo EM182 10mm capsules)
* TinySpHEAR_EM200.scad (Primo EM200 10mm capsules)

We assume that you are building a complete microphone assembly with phantom power balanced interfaces and a 12 pin DIN connector. If you want to build a microphone with a different capsule copy one of the files and start by modifying the capsule dimensions as measured from your selected capsule.

Each file has one line statements that render each component of the microphone and are "commented out" by a leading "\*". If you load the file into Openscad and remove the leading "\*" from one of the lines you should be able to preview the part by pressing "F5" (or do a full rendering by pressing "F6").

For building a TinySpHEAR four capsule Ambisonics microphone you will need to 3D print: 

* microphone body ("render_tetra_body"), holds four phantom power printed circuit boards
* upper flare to capsule array ("render_tetra_capsule_flare")
* lower flare to DIN connector ("render_tetra_connector_flare")
* two top capsules ("render_tetra_capsule_top")
* two bottom capsule holders ("render_tetra_capsule_bot")

If you add the TinySpHEAR shock mount with adaptor for Quik-Release KQ-2B microphone adapter:

* adapter to Quik-Release clip-on stand ("render_tetra_shock_mount_stand")
* shock mount external ring ("render_tetra_shock_mount_external_ring")
* shock mount internal top ring ("render_tetra_shock_mount_internal_ring_bot")
* shock mount internal bottom ring ("render_tetra_shock_mount_internal_ring_top")
* four shock mount internal ring connectors ("render_tetra_shock_mount_ring_connectors")

For each part you need to print you will have to export the rendered part to STL in Openscad, then load the STL code into your slicer (Cura in our case) and save the G-code generated by the slicer. The G-code will drive the printing process.

## Assembling the printed circuit boards

The printed circuit boards as milled by OtherMill are a little fragile. The traces are quite thin and can be lifted by pushing on soldered components. So, for the biggest ones (all four capacitors) I recommend using a small glue gun to put a drop of glue on the component before positioning it on the PCB so that it will not move once soldered (you have to be pretty fast when doing this).

Also make sure the two transistors are close to the PCB and leaning towards the center of the PCB, otherwise fitting of all four PCBs inside the microphone body might not be possible (there is not a lot of clearance - I tried to make the body as small as possible).

Once the boards are assembled test them!

It is best to prepare a set of "test components". Select one of the capsules and solder a length of Mogami W2490 cable to it (red to "Drain", white to "Source", shield to "Ground"). Also solder a length of Mogami W2490 cable to one of the XLR connectors (red to pin 2, white to pin 3, shield to pin 1).

Now test each of the boards by soldering the capsule and XLR cable, connect them into a preamplifier and check that it works.

Also test all capsules separately as well (you do not want to finish building the microphone and discover that one of the assemblies is not working - believe me, it is not fun).

Make sure that the PCBs fit into the printed microphone body. Depending on the print and PCB tolerances you may need to ligthly and carefully sand the sides of the PCBs so that they fit inside. You want a snug fit so that the PCB does not slide out by itself. Be careful when inserting them into the body (do not bend them). 

## Assembling the microphone

At this point we have all the 3D printed parts and we verified they fit together. You may need to use the needle files and/or the X-Acto knife to trim away imperfections. Make sure the inside of the capsule holders are free of burs and that the capsules have a tight fit. 

The first step is to glue together the four capsule holders and mount them on top of the capsule array mount. I have used 5 minute two part epoxy, but it sets almost too fast so you have to work quicky and precisely. You may want to use something that takes longer to set.

First snap the four capsule holders together. Apply epoxy to the inside of the mounting slots on the top of the capsule array mount and to the curved surfaces on which the two bottom capsules rest. Clip the four capsules into the array mount. Remove the upper two capsules gently and apply glue to the inside of all connection fingers. Remount them and press everything together carefully. Look at the geometry of the array from the side and top. This is your chance to align everything properly and make sure the array is symetrical. Keep holding the array until the glue sets. 

Solder a length of Mogami W2490 wire to each capsule, strip and pre-tin both ends. Mark each wire with one through four strips with a indelible pen so that you know which one is which. The small bump in the microphone stalk below the capsules is the "back" of the microphone. Capsule #1 is the "front upper left" capsule, capsule #2 is the "front lower right" capsule, #3 is the "back lower left" capsule and #4 is the "back upper right" capsule. 

To solder the cable to the capsule I find it easiest to strip and pre-tin all three wires, then form and cut the shield wire into a tiny "L" and solder the bottom of the "L" into the ground pad so that the wire is straight. Then carefully position the red and white wires (pre-cut to lenght) and solder them to the other two pads. Make sure the wires do not obstruct the tiny holes in the back of the capsules (those make the microphone into a cardiod)

Insert that capsules into the capsule holders. I start with the two bottom capsules. Thread the wire through the array mount hole that is closest to the center and push it down gently with a long nosed plier. Eventually you will be able to seat the capsule into the holder and push it in position. Do that with both of the bottom capsules. Then do the same with top capsules (much easier).

Insert the four PCBs into the body of the microphone and find some way to hold the whole thing securely (you need a lot of hands). Solder the microphone wires to the pads on the outside of the PCBs.

Now solder four lengths of Mogami W2490 cable to all 12 pins of the DIN connector. This is precision work and quite difficult to do cleanly. Of the four three pin groups the ones where one pin is "inside" are the most difficult. Start with that pin. Once you have all four wires soldered assemble the other half of the connector, thread the threaded ring and insert the connector into the bottom flare of the microphone threading the wires into it. Use the screws that are normally used to secure the strain relief to screw the connector to the mount.

Now solder all four cables to the bottom of the four PCBs in the microphone body. Carefully push together all three sections of the microphone until they click. 

Finally build the cable, again strip and pre-tin the Mogami W2931 cable, solder it to the 12 pin DIN connector (do not forget to thread all the parts before you start!) and assemble the whole thing. You will have to refer to the assembly drawings to fit everything together nicely.

Solder the four XLR connectors to the other end of the cable.

Connect all four connectors to your microphone preamplifier or recorder and make sure everything works. Label the XLR connectors appropriately by gently tapping on the capsules and making sure they are connected to the preamp in the right order.

And now on to the calibration!

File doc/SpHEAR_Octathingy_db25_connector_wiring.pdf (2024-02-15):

View from top

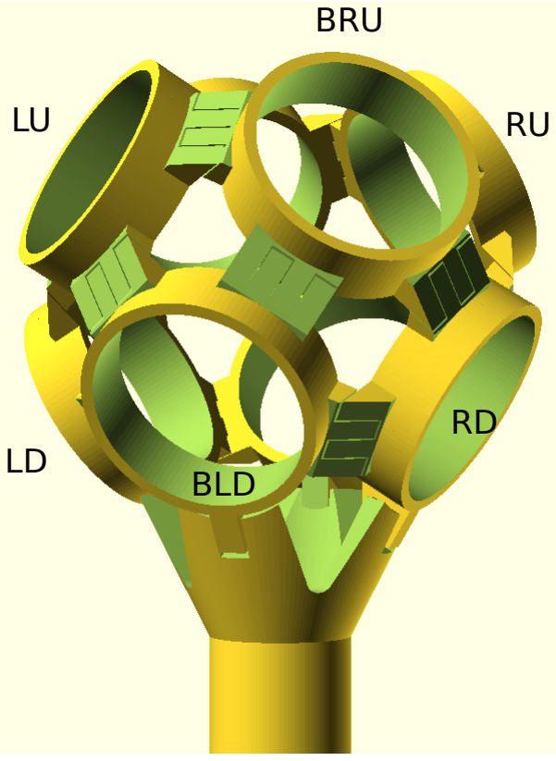
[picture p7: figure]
BRU; BLD
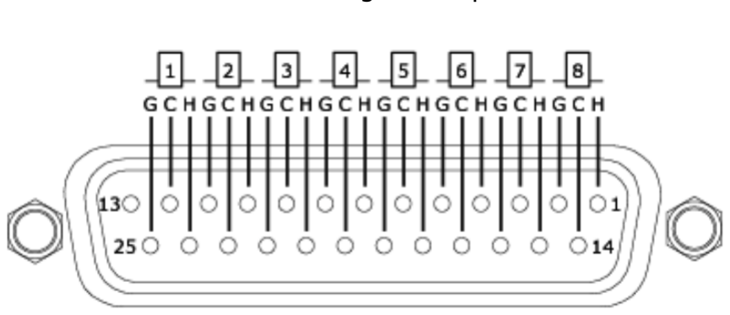
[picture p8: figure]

FLU #1 GND -> 25 1G -> XLR 1 = GND
FLU #1 + | -> 24 1C -> XLR 2 = +
FLU #1 - | -> 12 1H -> XLR 3 = -

FRD #2 GND -> 11 2G -> XLR 1 = GND
FRD #2 + | -> 23 2C -> XLR 2 = +
FRD #2 - | -> 10 2H -> XLR 3 = -

RU #3 GND -> 22 3G -> XLR 1 = GND
RU #3 + | -> 09 3C -> XLR 2 = +
RU #3 - | -> 21 3H -> XLR 3 = -

RD #4 GND -> 08 4G -> XLR 1 = GND
RD #4 + | -> 20 4C -> XLR 2 = +
RD #4 - | -> 07 4H -> XLR 3 = -

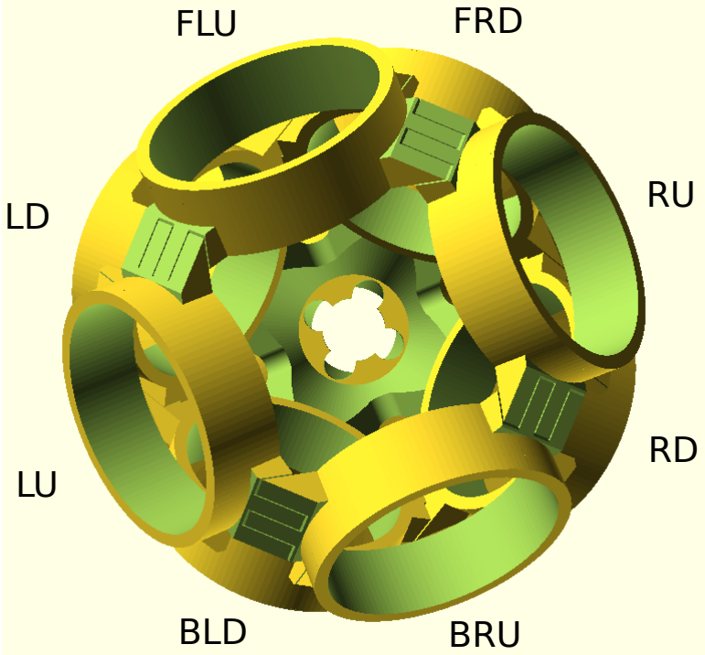
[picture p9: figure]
FLU; FRD; BLD; BRU

BRU #5 GND -> 19 5G -> XLR 1 = GND
BRU #5 + | -> 06 5C -> XLR 2 = +
BRU #5 - | -> 18 5H -> XLR 3 = -

BLD #6 GND -> 05 6G -> XLR 1 = GND
BLD #6 + | -> 17 6C -> XLR 2 = +
BLD #6 - | -> 04 6H -> XLR 3 = -

LU #7 GND -> 16 7G -> XLR 1 = GND
LU #7 + | -> 03 7C -> XLR 2 = +
LU #7 - | -> 15 7H -> XLR 3 = -

LD #8 GND -> 02 8G -> XLR 1 = GND
LD #8 + | -> 14 8C -> XLR 2 = +
LD #8 - | -> 01 8H -> XLR 3 = -

View from back

Tascam Analog DB-25 pinout

SpHEAR Project: Octathingy DB25 connector pin assignments

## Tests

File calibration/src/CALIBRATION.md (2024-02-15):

# The *SpHEAR Project

This file details the current calibration procedure for the TinySpHEAR B format 1st order microphone.

## Measurements

Requirements for a successful calibration:

* speaker: a single driver full frequency response speaker, best if not ported (we have used a H&K M50 with a frequency response of 100 to 20KHz +/- 5dB). 

* reference microphone: a decent reference microphone, hopefully one that has been calibrated so that the frequency response is known.

* impulse response measurement software (we have used Aliki running under Linux).

* ambisonics microphone, of course, and suitable four channel recorder. This is important: you need to use a microphone preamplifier with digitally controlled input gain (and with good tracking between channels). Anything with analog controls is not suitable as the calibration depends on repeatable and exact gains being maintained at all times between all four channels. You would be forced to use them at maximum or minimum gain which is very suboptimal. It is best to pair the microphone with a particular preamplifier or recorder and calibrate them as a unit. 

The software calibration requires at least 16 impulse response measurements at regular angle intervals in the horizontal plane. These should be recorded in a suitable space, either an anechoic chamber or a large space in which the first reflections are delayed enough so that they can be removed from the impulse response. Once you have them you can proceed with the rest of the calibration.

## Calibration

* calculate all A2B matrixes as a function of frequency (returned in A2BF).

```octave
[F FE A2BF PVF] = sphear_a2b_all((1:16), 300, 20000, 3, 48000, 256, 32, 0);
```

The last parameter can be used to enable the b format component polar plots.

The first parameter specifies the measurements to process, (1:16) is a vector that contains all measurement numbers. To specify a subset of measurements just build an array with the desired numbers. 

```octave
[F FE A2BF PVF] = sphear_a2b_all([1, 5, 9, 13, 15], 300, 20000, 3, 48000, 256, 32, 0);
```

Then design the FIR filter to correct each component of the A2B matrix as a function of frequency for low and mid frequencies (below 5000Hz in this example). Also restrict the maximum boost of the filter to 12 dB in this example. 

```octave
FIR = sphear_fir_design(F, A2BF, 256, 12, 48000, 5000);
```

Now plot, for each measurement, the B format signals as recovered after passing through the FIR filter, and also write a B-format soundfile of the rendered result. 

```octave
sphear_fir_render(FIR, 300, 20000, 8192, 128, 48000, 1);
```

Now calculate the power envelope for all B format components, normalize everything to (arbitrarily) the average power of W between 600 and 1200Hz. And optionally display the polar plots of W, X, Y and Z for each frequency band.

```octave
[B] = sphear_a2b_fir_all(300, 20000, 3, 8192, 48000, 1);
```

Extract the frequency response shapes from the B array. The second argument specifies whether to average all measurements (1) or only the on axis measurements (0). 

```octave
[W X Y Z] = sphear_fir_extract(B, 1, 1);
```

Redesign the FIR filter using the extracted W, X, Y and Z shapes. The lower frequency range (below 5000Hz in this example) will directly use the A2B matrix coefficients to design the frequency response shape, the upper frequency range will use an interpolated polynomial over the average frequency response of each component as calculated above. 

```octave
FIR = sphear_fir_design(F, A2BF, 256, 12, 48000, 5000, W, X, Y, Z);
```

Filter all capsule inputs through the B format conversion, write a B-format four channel soundfile to disk:

```octave
sphear_fir_render(FIR, 300, 20000, 8192, 128, 48000, 1);
```

Finally, plot all the b format component polar plots. The amplitude of the plots is normalized by the power of the W signal between 600 and 1200Hz. Frequency range considered is between 300Hz and 20KHz, the FFT size is 8192, sampling rate 48000, measurements done in 1/3 octave increments (approximately)

```octave
[B] = sphear_a2b_fir_all(300, 20000, 3, 8192, 48000, 1);
```

FIR contains a 4 x 4 matrix, each cell contains a FIR filter, applying those to each one of the four A format components coming from the microphone will generate 4 B format calibrated outputs.

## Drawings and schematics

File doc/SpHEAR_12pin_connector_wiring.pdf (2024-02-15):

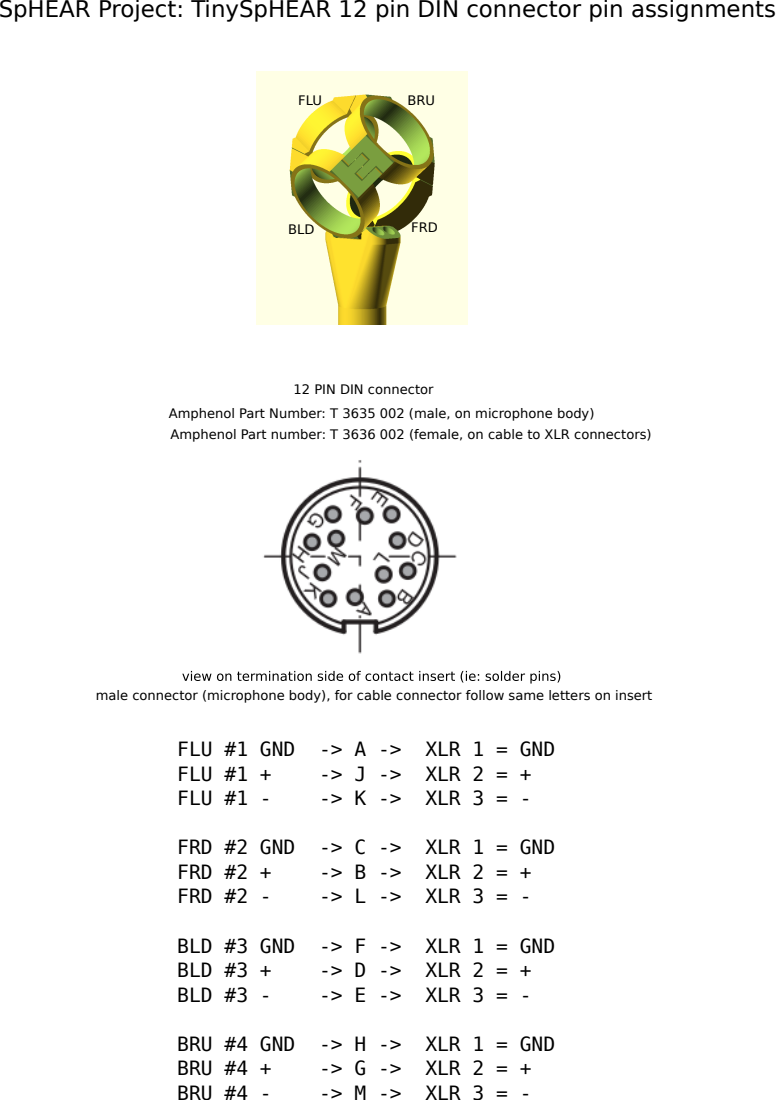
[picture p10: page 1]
FLU #1 +; -> J -> XLR 2 = +; FLU #1 -; -> K -> XLR 3 = -; FRD #2 +; -> B -> XLR 2 = +; FRD #2 -; -> L -> XLR 3 = -; BLD #3 +; -> D -> XLR 2 = +; BLD #3 -; -> E -> XLR 3 = -; BRU #4 +; -> G -> XLR 2 = +; BRU #4 -; -> M -> XLR 3 = -; FLU; BLD; FRD; BRU

SpHEAR Project: TinySpHEAR 12 pin DIN connector pin assignments

12 PIN DIN connector

Amphenol Part Number: T 3635 002 (male, on microphone body)
Amphenol Part number: T 3636 002 (female, on cable to XLR connectors)

male connector (microphone body), for cable connector follow same letters on insert

FLU #1 GND -> A -> XLR 1 = GND

FRD #2 GND -> C -> XLR 1 = GND

BLD #3 GND -> F -> XLR 1 = GND

BRU #4 GND -> H -> XLR 1 = GND

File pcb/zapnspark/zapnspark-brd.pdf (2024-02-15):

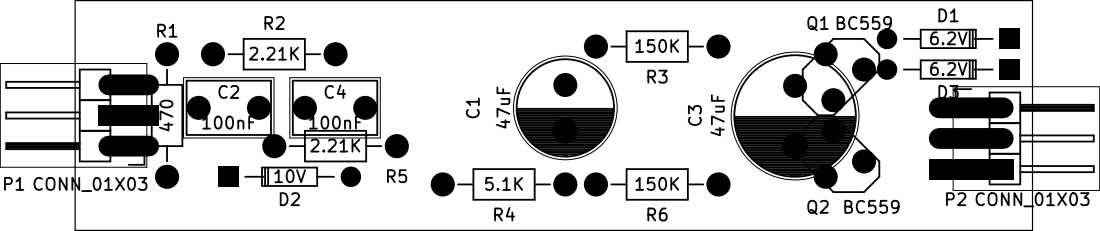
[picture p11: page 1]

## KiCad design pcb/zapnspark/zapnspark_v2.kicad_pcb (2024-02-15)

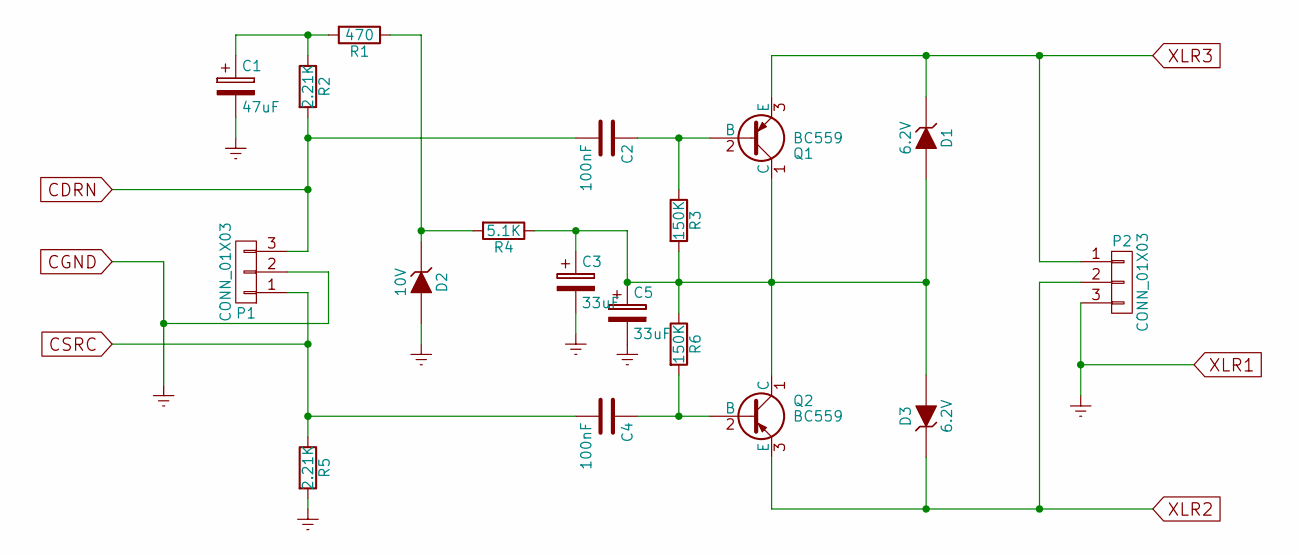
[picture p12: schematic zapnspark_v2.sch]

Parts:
C1: 47uF; C_Radial_D8_L13_P3.8
C2, C4: 100nF; C_Rect_L13_W4_P10
C3, C5: 33uF; C_Radial_D8_L13_P3.8
D1, D3: 6.2V; D5
D2: 10V; D5
P1, P2: CONN_01X03; Pin_Header_Angled_1x03
Q1, Q2: BC559; TO-220_Bipolar-BCE_Vertical
R1: 470; Resistor_Horizontal_RM10mm
R2, R5: 2.21K; Resistor_Horizontal_RM10mm
R3, R6: 150K; Resistor_Horizontal_RM10mm
R4: 5.1K; Resistor_Horizontal_RM10mm

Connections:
CDRN: C2.2, P1.3, R2.2
CGND: C1.2, C3.2, C5.2, D2.2 (A), P1.2, P2.3, R5.2
CSRC: C4.2, P1.1, R5.1
unnamed: C1.1, R1.2, R2.1
unnamed: C2.1, Q1.2 (B), R3.1
unnamed: C3.1, C5.1, D1.2 (A), D3.2 (A), Q1.1 (C), Q2.1 (C), R3.2, R4.1, R6.1
unnamed: C4.1, Q2.2 (B), R6.2
unnamed: D2.1 (K), R1.1, R4.2
XLR2: D3.1 (K), P2.2, Q2.3 (E)
XLR3: D1.1 (K), P2.1, Q1.3 (E)

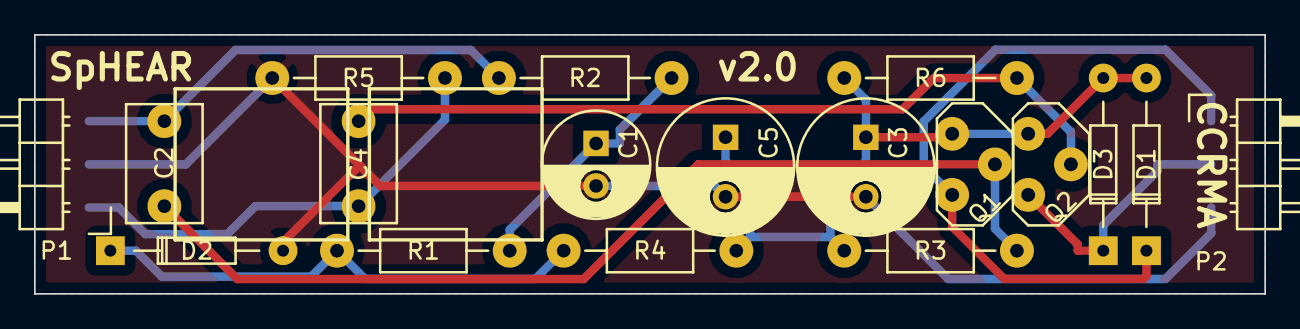
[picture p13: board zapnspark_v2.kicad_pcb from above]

Board: 2 copper layers, 72.4 x 15.2 mm, 18 parts (0 on the bottom side), 10 nets.
